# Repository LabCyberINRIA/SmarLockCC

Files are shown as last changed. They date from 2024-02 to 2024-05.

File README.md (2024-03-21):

Printed Circuit Board designed with Kicad to control an electrical lock.
It has a microcontroller (ESP32-C3) capable of bluetooth, WiFi and USB, a connector for a RFID reader board based on NXP MFRC522 chip, a servomotor connector and RGB LED.

Schematics
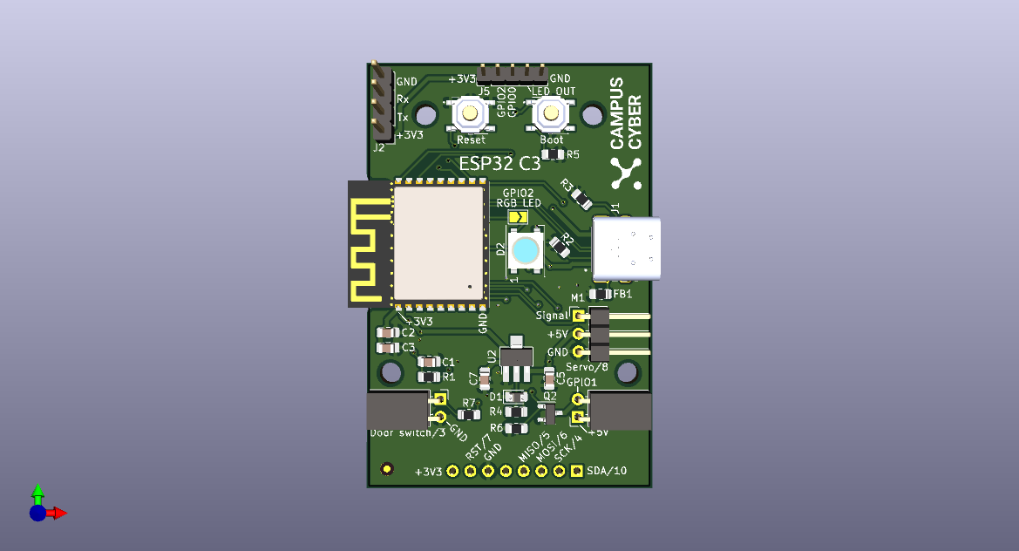
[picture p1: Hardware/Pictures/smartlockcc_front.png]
PCB-3D-Front

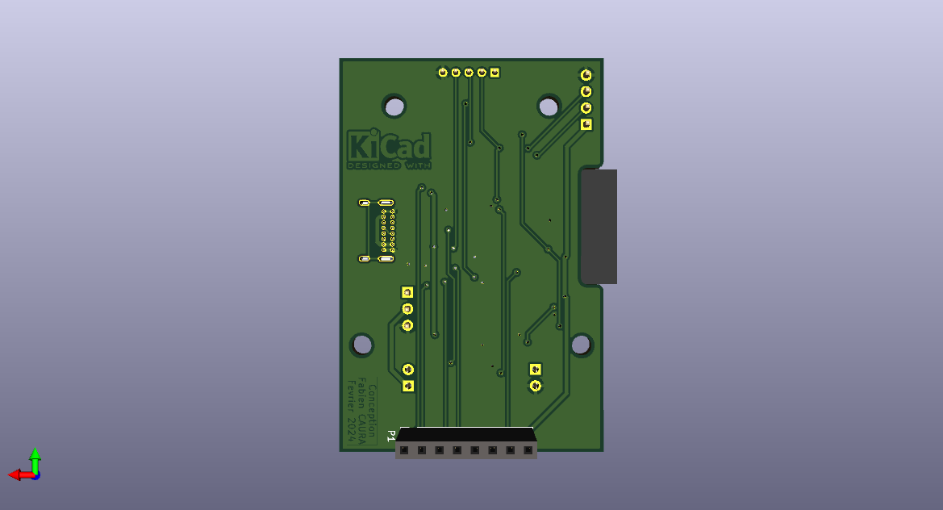
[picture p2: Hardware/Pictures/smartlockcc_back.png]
PCB-3D-Back


To program the board using Arduino IDE, you need to add the ESP32 support https://docs.espressif.com/projects/arduino-esp32/en/latest/installing.html

Connect your board and select the "Adafruit QT Py ESP32-C3" board, and the port that should appear. The first time or if the port does not appear, you need to put manually your board in download mode : push the boot button, power or reset the board, then release the boot button.

You should be able to flash an example to the board.

For the LED, you can use the Adafruit NeoPixel library, test it with RGBWstrandtest example configured with the LED_PIN set to 2 and LED_COUNT set to 1

For the RFID board, the RST_PIN is 7, SS_PIN is 10, and SPI.begin(4, 5, 6, 10).

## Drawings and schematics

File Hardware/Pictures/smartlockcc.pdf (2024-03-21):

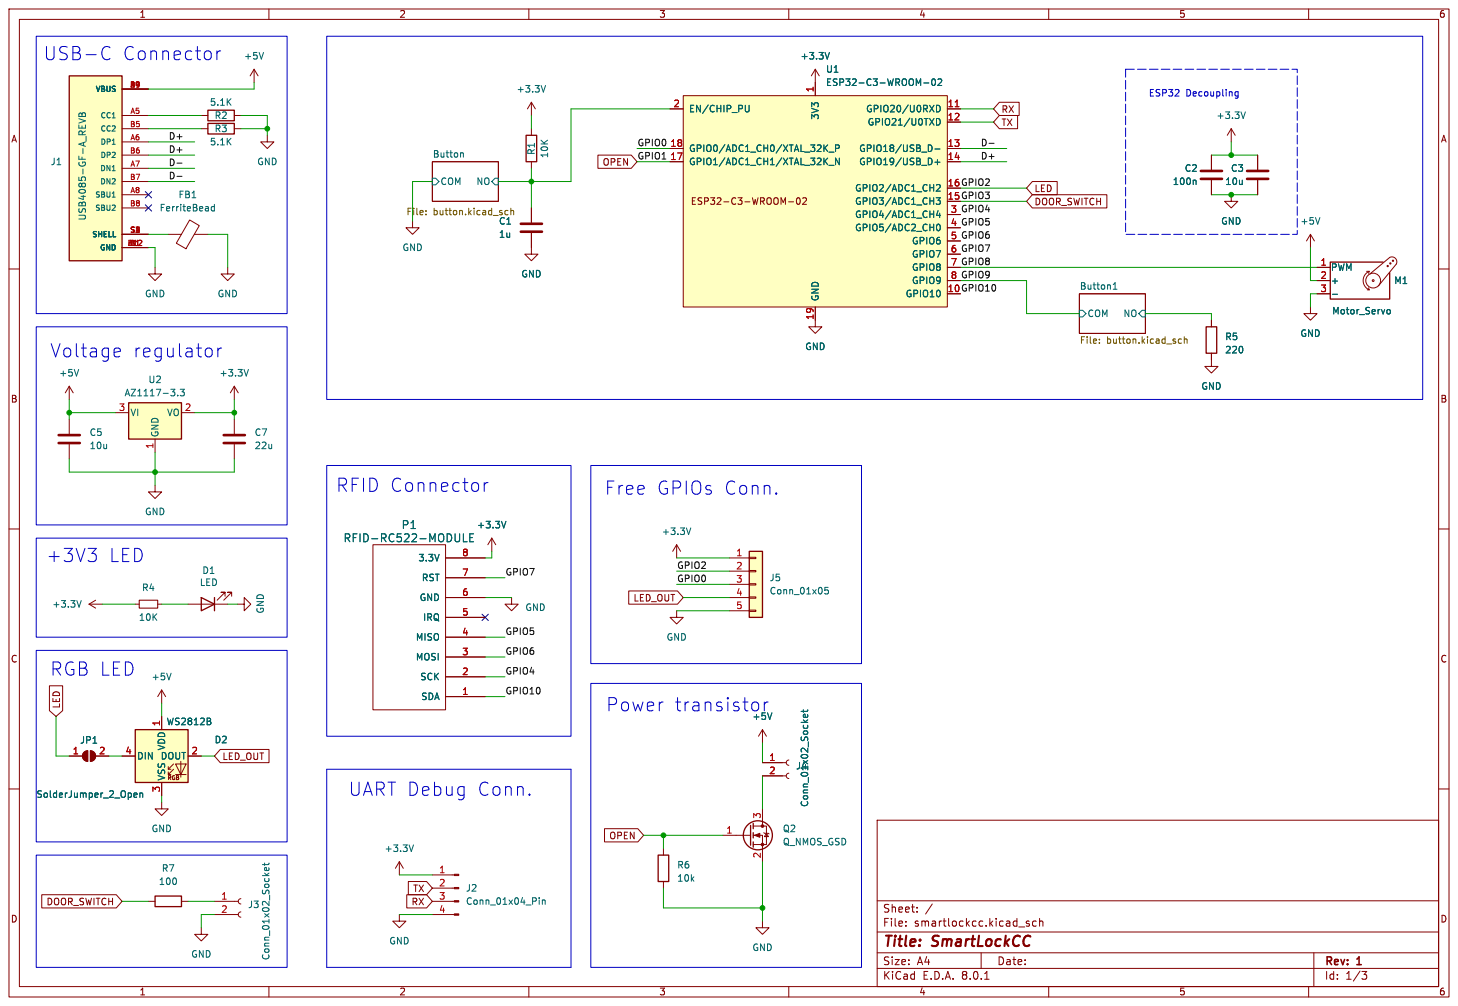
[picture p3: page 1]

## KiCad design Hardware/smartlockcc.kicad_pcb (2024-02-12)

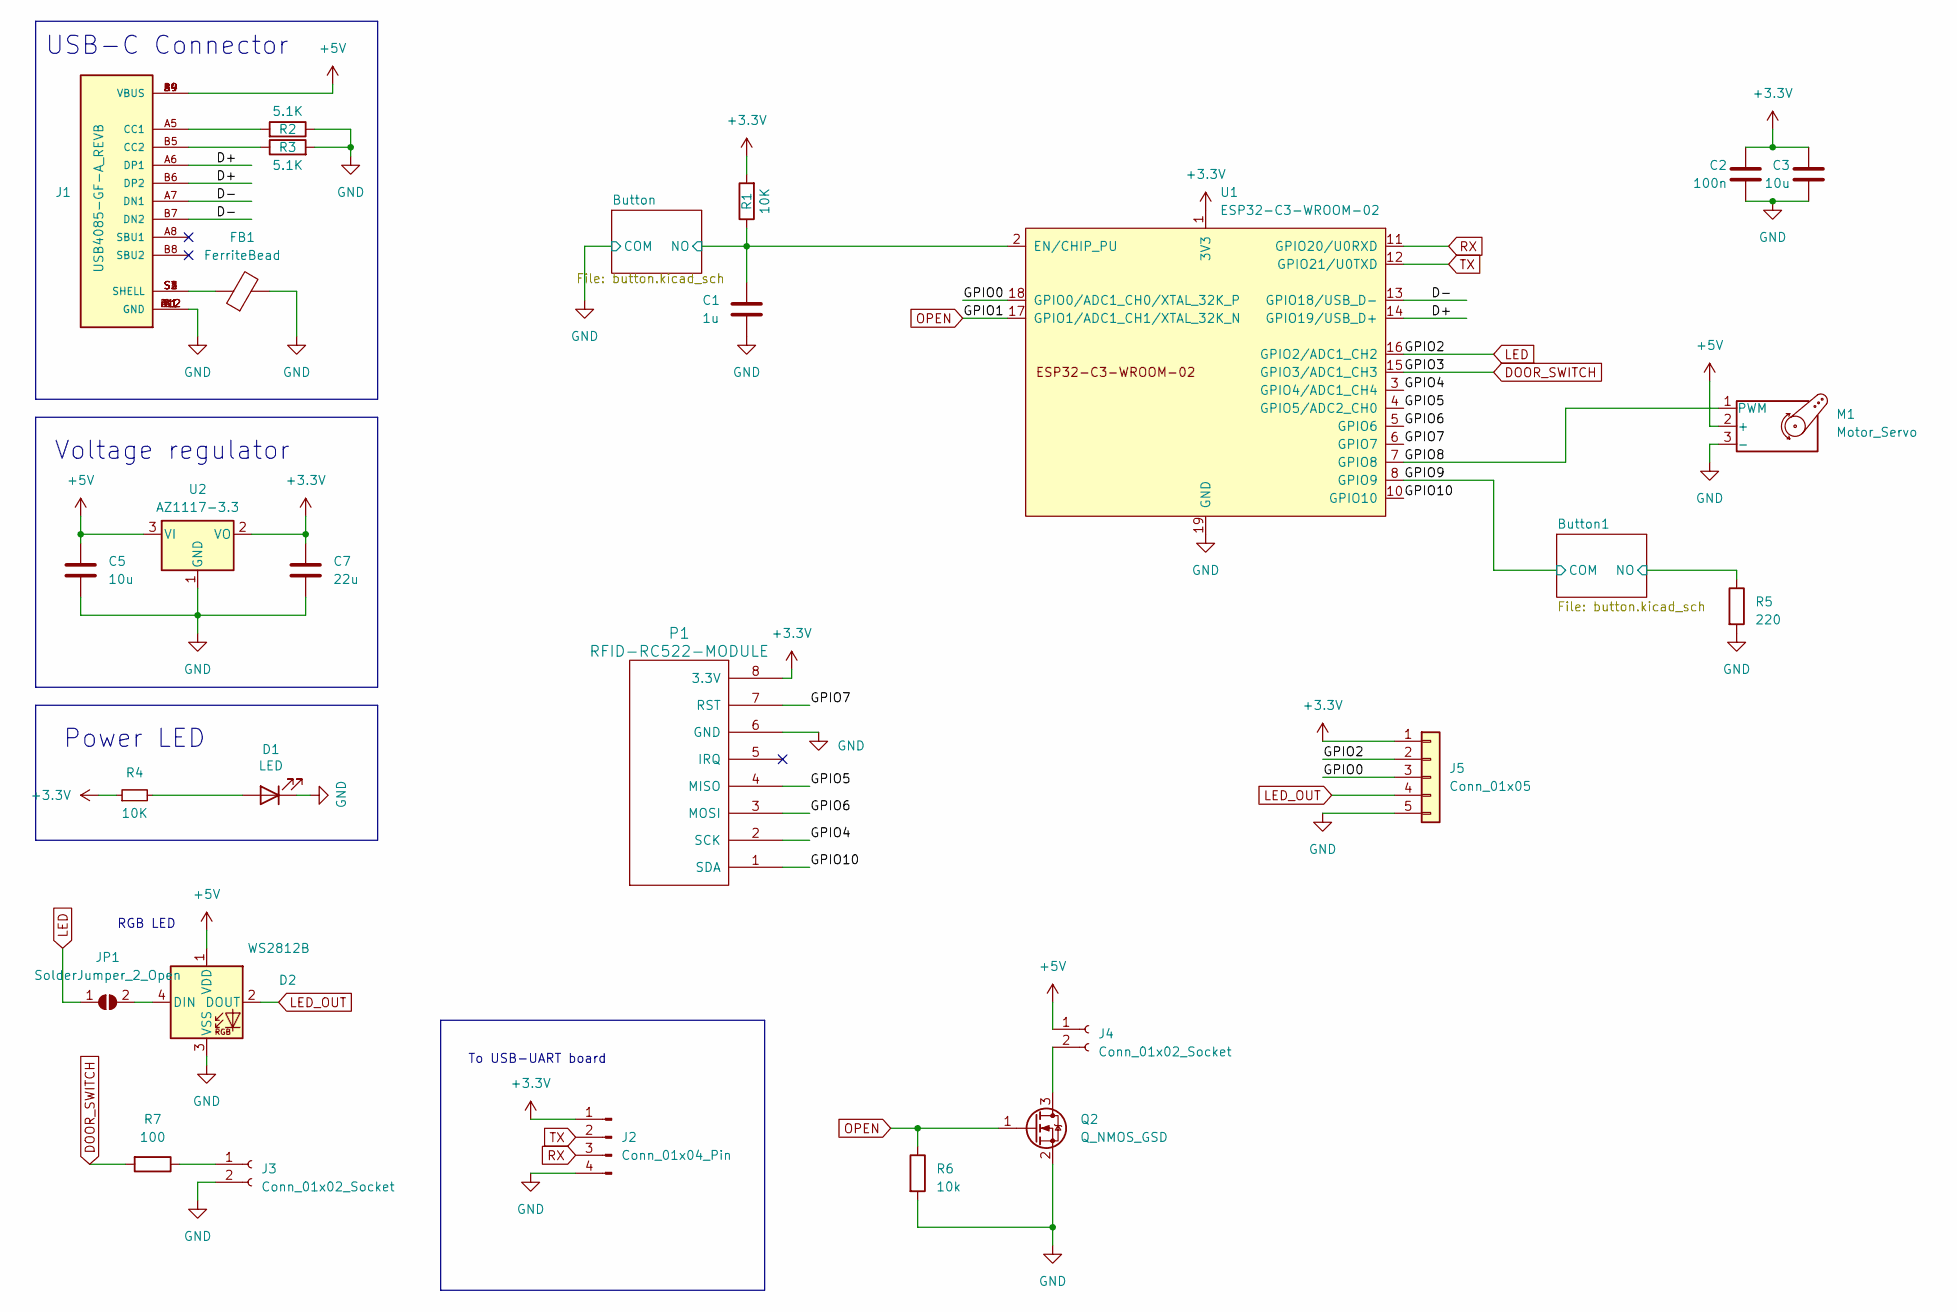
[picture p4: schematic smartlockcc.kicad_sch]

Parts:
C1: 1u; C_0805_2012Metric_Pad1.18x1.45mm_HandSolder
C2: 100n; C_0805_2012Metric_Pad1.18x1.45mm_HandSolder
C3, C5: 10u; C_0805_2012Metric_Pad1.18x1.45mm_HandSolder
C7: 22u; C_0805_2012Metric_Pad1.18x1.45mm_HandSolder
D1: LED; D_0805_2012Metric_Pad1.15x1.40mm_HandSolder; Manufacturer_Part_Number VSMB1940X01; Mouser Part Number 782-VSMB1940X01
D2: WS2812B; LED_WS2812B_PLCC4_5.0x5.0mm_P3.2mm
FB1: FerriteBead; R_0805_2012Metric_Pad1.20x1.40mm_HandSolder
J1: USB4085-GF-A_REVB; GCT_USB4085-GF-A_REVB; PARTREV B
J2: Conn_01x04_Pin; PinHeader_1x04_P2.54mm_Vertical
J3, J4: Conn_01x02_Socket; PinSocket_1x02_P2.54mm_Horizontal
J5: Conn_01x05; PinHeader_1x05_P2.00mm_Vertical
JP1: SolderJumper_2_Open; SolderJumper-2_P1.3mm_Open_TrianglePad1.0x1.5mm
M1: Motor_Servo; PinHeader_1x03_P2.54mm_Horizontal
P1: RFID-RC522-MODULE; PinSocket_1x08_P2.54mm_Vertical
Q2: Q_NMOS_GSD; SOT-23-3
R1: 10K; R_0805_2012Metric_Pad1.20x1.40mm_HandSolder
R2, R3: 5.1K; R_0805_2012Metric_Pad1.20x1.40mm_HandSolder
R4: 10K; R_0805_2012Metric_Pad1.20x1.40mm_HandSolder; MPN DNP
R5: 220; R_0805_2012Metric_Pad1.20x1.40mm_HandSolder
R6: 10k; R_0805_2012Metric_Pad1.20x1.40mm_HandSolder
R7: 100; R_0805_2012Metric_Pad1.20x1.40mm_HandSolder
U1: ESP32-C3-WROOM-02
U2: AZ1117-3.3; SOT-89-3_Handsoldering

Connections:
+3.3V: C2.1, C3.1, C7.1, J2.1, J5.1, P1.8 (3.3V), R1.2, R4.1, U1.1 (3V3), U2.2 (VO)
+5V: C5.1, D2.1 (VDD), J1.A4 (VBUS), J1.A9 (VBUS), J1.B4 (VBUS), J1.B9 (VBUS), J4.1, M1.2 (+), U2.3 (VI)
/Button1/NO: R5.1; also elsewhere on the board
/Button/NO: C1.1, R1.1, U1.2 (EN/CHIP_PU); also elsewhere on the board
/D+: J1.A6 (DP1), J1.B6 (DP2), U1.14 (GPIO19/USB_D+)
/D-: J1.A7 (DN1), J1.B7 (DN2), U1.13 (GPIO18/USB_D-)
/GPIO0: J5.3, U1.18 (GPIO0/ADC1_CH0/XTAL_32K_P)
/GPIO4: P1.2 (SCK), U1.3 (GPIO4/ADC1_CH4)
/GPIO5: P1.4 (MISO), U1.4 (GPIO5/ADC2_CH0)
/GPIO6: P1.3 (MOSI), U1.5 (GPIO6)
/GPIO7: P1.7 (RST), U1.6 (GPIO7)
/GPIO8: M1.1 (PWM), U1.7 (GPIO8)
/GPIO9: U1.8 (GPIO9); also elsewhere on the board
/GPIO10: P1.1 (SDA), U1.10 (GPIO10)
DOOR_SWITCH: R7.2, U1.15 (GPIO3/ADC1_CH3)
GND: C1.2, C2.2, C3.2, C5.2, C7.2, D1.1 (K), D2.3 (VSS), FB1.2, J1.A1 (GND), J1.A12 (GND), J1.B1 (GND), J1.B12 (GND), J2.4, J3.2, J5.5, M1.3 (-), P1.6 (GND), Q2.2 (S), R2.1, R3.2, R5.2, R6.2, U1.9 (GND), U1.19 (GND), U2.1 (GND); also elsewhere on the board
LED: J5.2, JP1.1 (A), U1.16 (GPIO2/ADC1_CH2)
LED_OUT: D2.2 (DOUT), J5.4
unnamed: D1.2 (A), R4.2
unnamed: D2.4 (DIN), JP1.2 (B)
unnamed: FB1.1, J1.S1 (SHELL), J1.S2 (SHELL), J1.S3 (SHELL), J1.S4 (SHELL)
unnamed: J1.A5 (CC1), R2.2
unnamed: J1.B5 (CC2), R3.1
unnamed: J3.1, R7.1
unnamed: J4.2, Q2.3 (D)
OPEN: Q2.1 (G), R6.1, U1.17 (GPIO1/ADC1_CH1/XTAL_32K_N)
RX: J2.3, U1.11 (GPIO20/U0RXD)
TX: J2.2, U1.12 (GPIO21/U0TXD)

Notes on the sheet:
Voltage regulator
Power LED
RGB LED
To USB-UART board
USB-C Connector

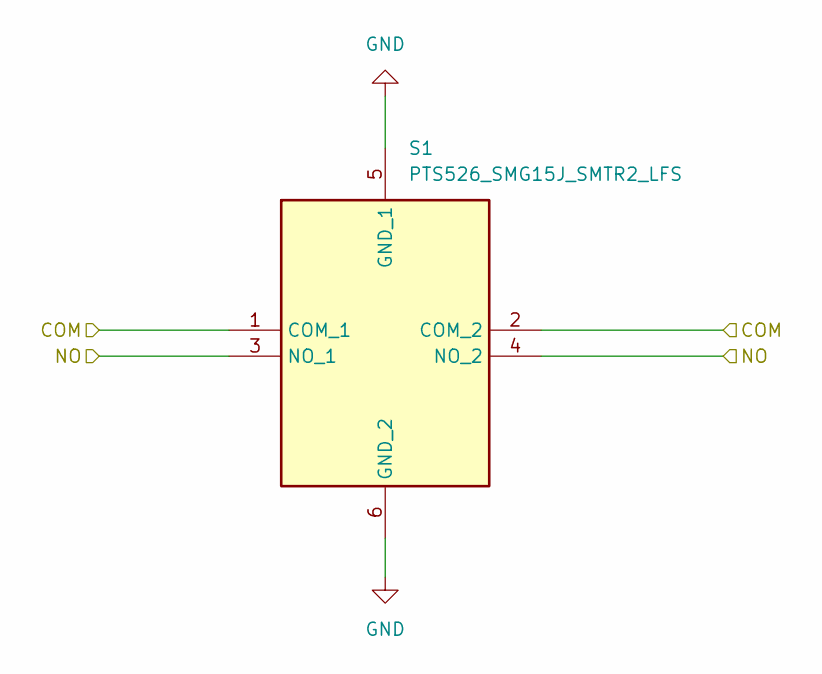
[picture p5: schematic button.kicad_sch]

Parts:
S1: PTS526_SMG15J_SMTR2_LFS; PTS526SMG15JSMTR2LFS; Manufacturer_Part_Number PTS526 SMG15J SMTR2 LFS; Mouser Part Number 611-TS526SMG15JSMR2L

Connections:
/Button/NO: S1.3 (NO_1), S1.4 (NO_2); also elsewhere on the board
GND: S1.1 (COM_1), S1.2 (COM_2), S1.5 (GND_1), S1.6 (GND_2); also elsewhere on the board

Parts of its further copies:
S2: PTS526_SMG15J_SMTR2_LFS; PTS526SMG15JSMTR2LFS; Manufacturer_Part_Number PTS526 SMG15J SMTR2 LFS; Mouser Part Number 611-TS526SMG15JSMR2L

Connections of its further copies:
/Button1/NO: S2.3 (NO_1), S2.4 (NO_2); also elsewhere on the board
/GPIO9: S2.1 (COM_1), S2.2 (COM_2); also elsewhere on the board
GND: S2.5 (GND_1), S2.6 (GND_2); also elsewhere on the board

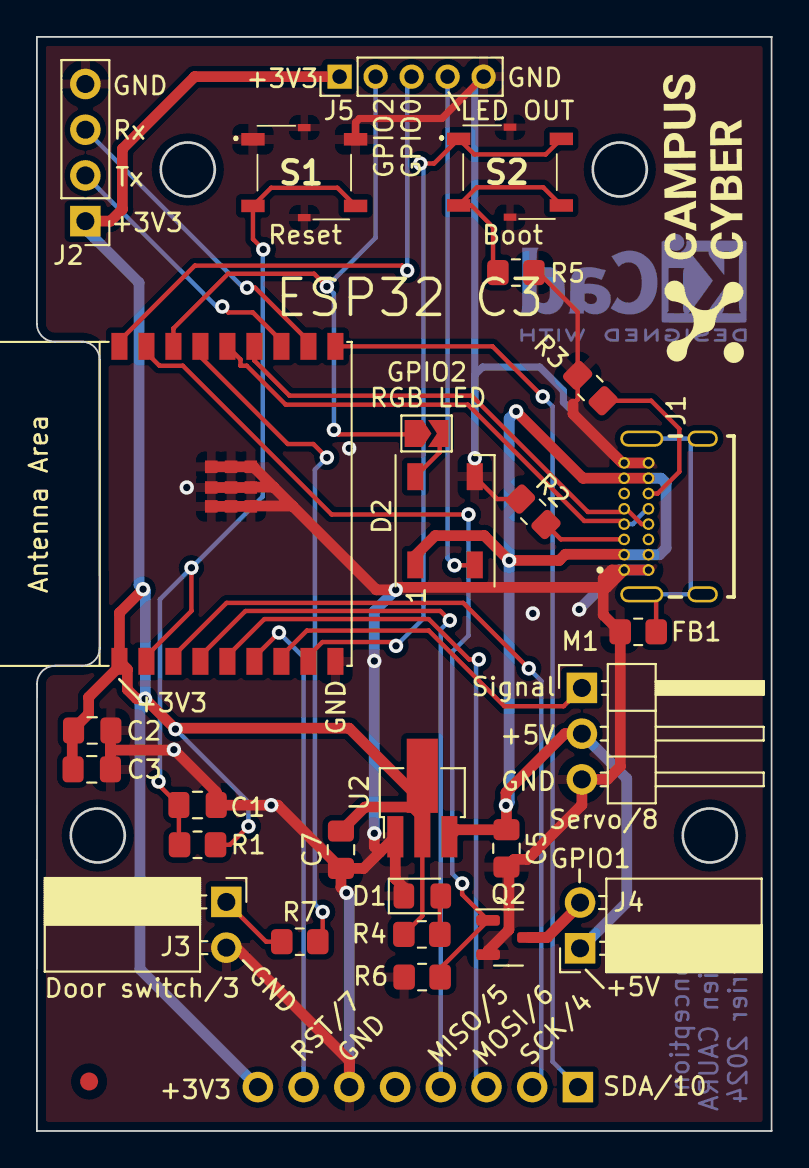
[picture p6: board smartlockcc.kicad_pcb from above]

Board: 2 copper layers, 40.8 x 60.8 mm, 28 parts (1 on the bottom side), 28 nets.

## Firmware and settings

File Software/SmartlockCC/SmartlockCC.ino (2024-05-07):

/* Example of code for the ESP32-C3 board with RFID, Servo and RGBW LED */

#define DEBUG
/* Servo */
#include <ServoStep.h>
#include "SmartlockCC.h"

ServoStep servo = ServoStep(8);

/* LED */
#include <Adafruit_NeoPixel.h>
#define LED_PIN 2
// How many NeoPixels are attached to the board?
#define LED_COUNT 1
// NeoPixel brightness, 0 (min) to 255 (max)
#define BRIGHTNESS 20  // Set BRIGHTNESS to about 1/5 (max = 255)

// Declare our NeoPixel strip object:
Adafruit_NeoPixel strip(LED_COUNT, LED_PIN, NEO_GRBW + NEO_KHZ800);
// Argument 1 = Number of pixels in NeoPixel strip
// Argument 2 = Arduino pin number (most are valid)
// Argument 3 = Pixel type flags, add together as needed:
//   NEO_KHZ800  800 KHz bitstream (most NeoPixel products w/WS2812 LEDs)
//   NEO_KHZ400  400 KHz (classic 'v1' (not v2) FLORA pixels, WS2811 drivers)
//   NEO_GRB     Pixels are wired for GRB bitstream (most NeoPixel products)
//   NEO_RGB     Pixels are wired for RGB bitstream (v1 FLORA pixels, not v2)
//   NEO_RGBW    Pixels are wired for RGBW bitstream (NeoPixel RGBW products)

/* RFID */
#include <SPI.h>
#include <MFRC522.h>
#define RST_PIN 7  // Configurable, see typical pin layout above
#define SS_PIN 10  // Configurable, see typical pin layout above

MFRC522 mfrc522(SS_PIN, RST_PIN);  // Create MFRC522 instance

void setup() {
#ifdef DEBUG
  Serial.begin(115200);  // Initialize serial communications with the PC
  while (!Serial)
    ;  // Do nothing if no serial port is opened (added for Arduinos based on ATMEGA32U4)
#endif
  // Servo
  servo.servoSet(15);  // Some servos don't like 0°
  // LED
  strip.begin();  // INITIALIZE NeoPixel strip object (REQUIRED)
  strip.show();   // Turn OFF all pixels ASAP
  strip.setBrightness(BRIGHTNESS);
  // RFID
  SPI.begin(4, 5, 6, 10);  //SCK, MISO, MOSI, SS);			// Init SPI bus
  mfrc522.PCD_Init();      // Init MFRC522
  delay(4);                // Optional delay. Some board do need more time after init to be ready, see Readme
#ifdef DEBUG
  mfrc522.PCD_DumpVersionToSerial();  // Show details of PCD - MFRC522 Card Reader details
  Serial.println(F("Scan PICC to see UID, SAK, type, and data blocks..."));
#endif
}

void loop() {
  uint64_t serial_card_num=0;
  bool granted=false;
  String name="";
  // Reset the loop if no new card present on the sensor/reader. This saves the entire process when idle.
  if (!mfrc522.PICC_IsNewCardPresent()) {
    strip.setPixelColor(0, strip.Color(255, 0, 0, 0));
    servo.servoSet(15);
    strip.show();
    return;
  }

  // Select one of the cards
  if (!mfrc522.PICC_ReadCardSerial()) {
    return;
  }
#ifdef DEBUG
  // Dump debug info about the card; PICC_HaltA() is automatically called
  //mfrc522.PICC_DumpToSerial(&(mfrc522.uid));
#endif
  for (byte i = 0; i < mfrc522.uid.size; i++) {
      /*if(mfrc522.uid.uidByte[i] < 0x10) {
        Serial.print(F(" 0"));
      } else {
        Serial.print(F(" "));
        Serial.print(mfrc522.uid.uidByte[i], HEX);
      }*/
    serial_card_num |= mfrc522.uid.uidByte[i];
    serial_card_num <<= 8;
  }

  for(int j=0; j<tablesize; j++) {
    if(serial_card_num == table[j].UID) {
      name=table[j].name;
      granted=true;
      break;
    }
  }
  if(granted) {
    Serial.print("Accès authorisé pour ");
    Serial.println(name);
    servo.servoSet(180);
    strip.setPixelColor(0, strip.Color(0, 255, 0, 0));
    strip.show();
    delay(2000);
  } else {
    Serial.print("Accès refusé pour UID : 0x");
    Serial.println(serial_card_num, HEX);
    delay(1000);
  }

}

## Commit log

2024-02-12 Files as sent to aisler, first batch
    [button.kicad_sch, smartlockcc.kicad_pcb, smartlockcc.kicad_sch]
2024-03-07 Test code added
    [button.kicad_sch, smartlockcc.kicad_pcb, smartlockcc.kicad_sch]
2024-03-21 Cleanup and pictures added
    [button.kicad_sch, smartlockcc.kicad_sch]
